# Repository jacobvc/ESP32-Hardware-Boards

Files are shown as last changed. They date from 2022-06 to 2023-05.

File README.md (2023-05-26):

# Esp32 Dev Module Hardware Boards
This repository contains hardware and circuit board designs to simplify ESP32 Dev Module peripheral device connectivity

I think that I have about average circuit board design and soldering skills for an (older) mechanical engineer. As currently, mostly a hobbiest developer, I tend to develop reusable functionality focused circuit boards as opposed to project specific circuit boards. My soldering skills are OK for 0.1 inch center parts. 0805 surface mount parts are at or beyond my limit.

I am sharing these eagle board designs that I have found to be useful; mostly as a sort of tidy bridge between a breadboard and a project specific design. Unless otherwise specified, they are for (30 pin) ESP32 Dev Module boards.

All of the boards are designed using eagle, and any of them can be ordered in many ways, including by going to the [OSH park web site](https://oshpark.com/) and uploading the appropriate .brd file

## Esp32 Dev Module Pins
This design consists of two 15 pin pin headers; ESP32-LEFT and ESP32-RIGHT, with wires and labels corresponding to pin functionality. They are not 'connected' to one-another and are generally intended to be used as a quick start in laying out a board for one or the other side of an ESP32 Dev Module. 

## [ESP32 Lcd 3.5 Connectors](Lcd3.5Connectors)
This design connects the right side of an ESP32 Dev Module (ESP32-RIGHT) to a LCD touch screen display. The display uses all of the GPIOs on that side except two. A four pin connector supports connecting the display mounted SD socket using a shared SPI. The two unused ports are routed to a four pin I2C connector. 

[Used with this display](http://www.lcdwiki.com/3.5inch_SPI_Module_ILI9488_SKU:MSP3520)

## [ESP32 I/O Adapter](Esp32IoAdapt)
This design connects the left side of an ESP32 Dev Module to JST ZH 1.5mm keyed connectors. 

The connectors include
0.1 inch connectors
* 1 each 2 pin GS connector  (switch)
* 1 each 3 pin GVS connector (servo motor, etc). 

JST ZH 1.5mm keyed connectors. 
* 2 each 3 pin GVI connectors (potentiometer, etc). 
* 1 each 4 pin GVSS connector (serial port, I2C, etc)
* 1 each 5 pin GVIIS connectors (joystick, misc)
* 1 each 5 pin GVSSS connectors (joystick, misc)

Note:
*  GVS.. == Ground / 3v3 / Sense GPIO
*  GVI.. == Ground / 3v3 / Input only GPIO
## [ESP32 Audio / Relay Adapter](Esp32Relays)
This design connects left side of an esp32 Dev Module to:
* A three channel relay board
* A CD4066 based analog switch. Two channels of the CD4066 are connected to 3.5mm TRS (input / output) audio connectors, and the other two are available on a pair of 0.1 in center 3 pin headers.
* A 3 pin G5VS connector intended to be used for Neopixel Matrix Display
* Two 3 pin GVS connectors available for general use

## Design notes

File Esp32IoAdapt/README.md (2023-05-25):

# ESP32 I/O Adapter

A relatively small footprint approach to make the I/O pins on the "LEFT_SIDE" of a ESP32 Dev Module available.

Consists of circuit board designs, a (src) header file, and examples.

## Boards
An Esp32IoAdapt board, supported by two other trivial boards to ease connectivity with thumb joysticks and slider potentiometers.

**Esp32IoAdapt** contains a ESP-32 "LEFT_SIDE" board that present the I/O pins on the left side of 
a ESP32 Dev Module as (mostly) JST ZH 1.5mm connectors.

**Joystick** contains a joystick adapter a joystick to the other end of a 5 pin connector.

**Slider** contains an adapter to mount and connect a 35mm slider potentiometer to the other end of a 3 pin connector.

### Esp32IoAdapt
0.1 inch connectors
* 1 each 2 pin GS connector  (switch)
* 1 each 3 pin GVS connector (servo motor, etc). 

JST ZH 1.5mm keyed connectors. The connectors include
* 2 each 3 pin GVI connectors (potentiometer, etc). 
* 1 each 4 pin GVSS connector (serial port, I2C, etc)
* 1 each 5 pin GVSSS connectors (joystick, misc)
* 1 each 5 pin GVIIS connectors (joystick, misc)

Note:
*  GVS.. == Ground / 3v3 / Sense GPIO
*  GVI.. == Ground / 3v3 / Input only GPIO
*  The "V" pins are all 3.3v, so they may not be suited for 5V devices such as 5V servo motors

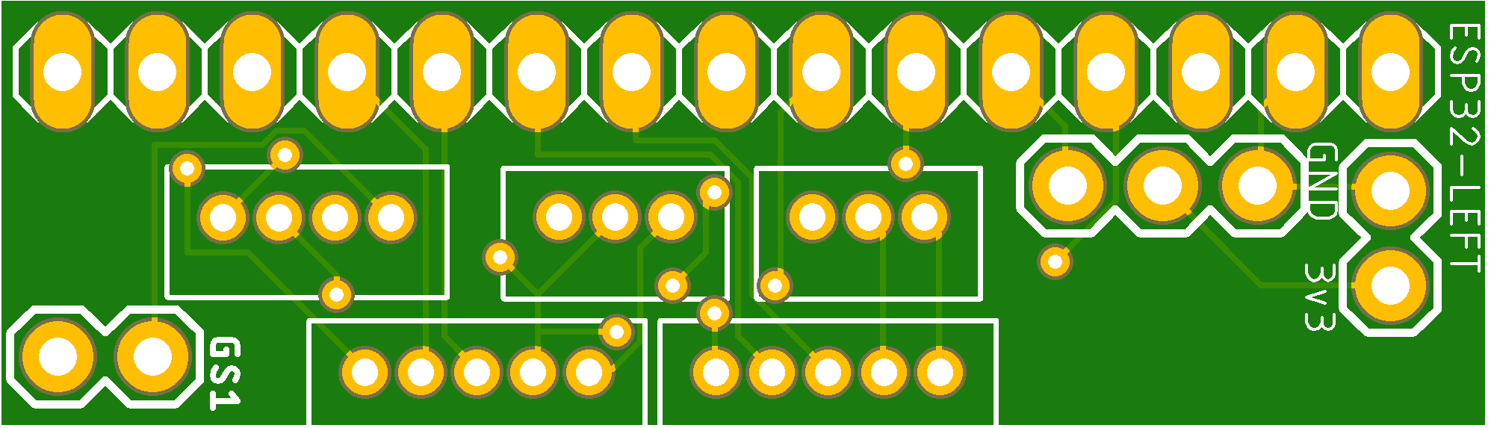
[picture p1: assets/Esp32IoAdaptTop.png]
Top Side Top View

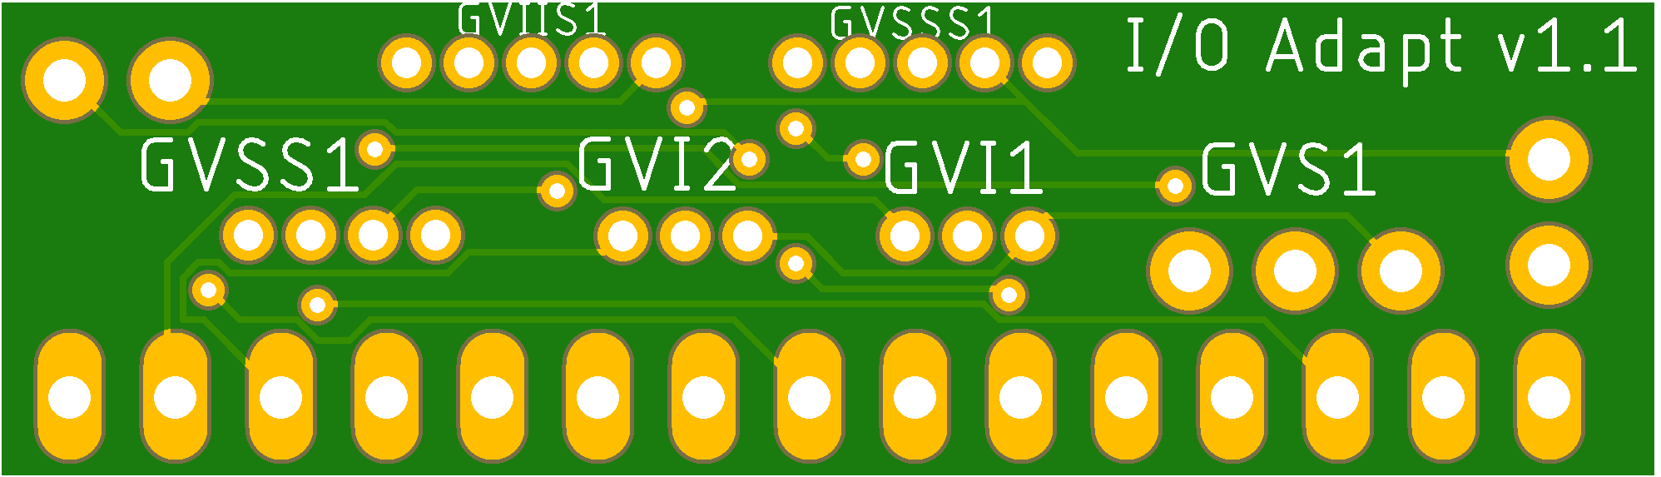
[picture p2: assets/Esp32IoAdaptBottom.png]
Bottom Side Bottom View

Intended to be used with pre-built JST-ZH cables. 
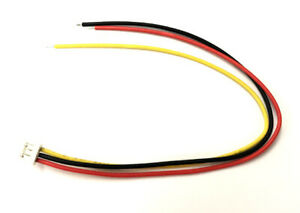
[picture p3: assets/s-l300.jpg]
Cable


### Joystick Adapter
A simple adapter board adapting straight through from 1.5 mm to 0.1 inch. Intended to connect thumb joystick via JST ZH connector 
or soldered wires from JST ZH cable.

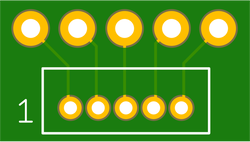
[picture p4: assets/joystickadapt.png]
Joystick adapter


### Slider Adapter
A simple adapter / mounting board for mounting a 35 mm slider potentiometer and connecting via JST ZH connector 
or soldered wires from JST ZH cable.

Slider
Slider adapter

## src
src contains the Esp32IoAdapt.h header file, presented as a component

# Examples
[Esp32IoAdapt is used for the examples](https://github.com/jacobvc/ESP-Object-Messaging/tree/main/examples) in ESP-Object-Messaging.

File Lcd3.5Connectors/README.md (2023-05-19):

# Lcd 3.5 Connectors (v4)
This design connects the right side of an ESP32 Dev Module to a LCD touch screen display. The display uses all of the GPIOs on that side except two. A four pin connector supports connecting the display mounted SD socket using a shared SPI. The two unused ports are routed to a four pin I2C connector. 

[Used with this display](http://www.lcdwiki.com/3.5inch_SPI_Module_ILI9488_SKU:MSP3520); Controller ili9488, Touch controller XPT2046

The hardware connections (for [LVGL V7 driver](https://github.com/lvgl/lv_port_esp32) is supported by these definitions in 'sdconfig'

    CONFIG_LV_TFT_DISPLAY_SPI_VSPI=y
    CONFIG_LV_DISP_SPI_MOSI=4
    # CONFIG_LV_DISPLAY_USE_SPI_MISO is not set
    CONFIG_LV_DISP_SPI_CLK=17
    CONFIG_LV_DISP_SPI_CS=19
    CONFIG_LV_DISP_PIN_DC=5
    CONFIG_LV_DISP_PIN_RST=18
    CONFIG_LV_TOUCH_DRIVER_PROTOCOL_SPI=y
    # CONFIG_LV_TOUCH_CONTROLLER_SPI_HSPI is not set
    CONFIG_LV_TOUCH_CONTROLLER_SPI_VSPI=y

    #
    # Touchpanel (XPT2046) Pin Assignments
    #
    CONFIG_LV_TOUCH_SPI_MISO=2
    CONFIG_LV_TOUCH_SPI_MOSI=4
    CONFIG_LV_TOUCH_SPI_CLK=17
    CONFIG_LV_TOUCH_SPI_CS=16
    # CONFIG_LV_TOUCH_PIN_IRQ is not set
    # end of Touchpanel (XPT2046) Pin Assignments

And separately to use the on-display-board SD Card Socket:

    #define LCD_BACKLIGHT_PIN 15
    #define SHARED_SPI_SD_CS_PIN 22
    #define SHARED_SPI_SD_HOST VSPI_HOST // same as LCD

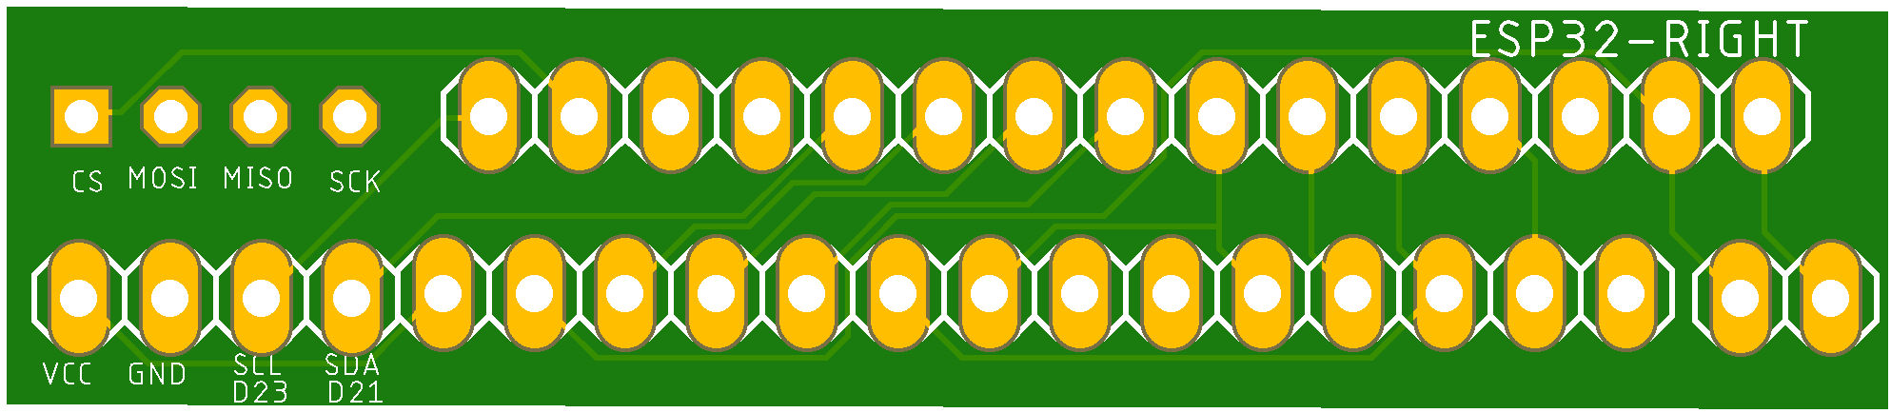
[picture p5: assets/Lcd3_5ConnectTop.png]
Top Side

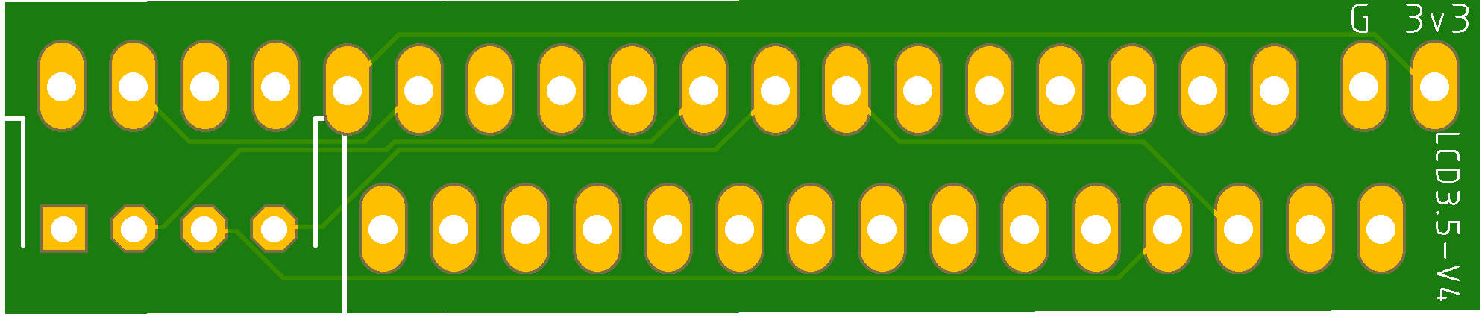
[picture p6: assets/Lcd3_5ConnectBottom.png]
Bottom Side


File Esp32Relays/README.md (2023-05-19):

# Esp32 Relays Board
This design utilizes the left side of an ESP32 Dev Module for:

* A three channel relay board
* A CD4066 based analog switch. Two channels of the CD4066 are connected to 3.5mm TRS (input / output) audio connectors, and the other two are available on a pair of 0.1 in center 3 pin headers.
* A 3 pin (Ground, 5V, and Data on D32) connector intended to be used for Neopixel Matrix Display
* Two 3 pin (Ground, 3.3v, D25 or D26) connectors available for general use

A 3 pin Power connector is provided for **REQUIRED 3.3v input** (from the other side of the ESP32) and optional 5V power for when the system is not being powered by the ESP32 built in USB

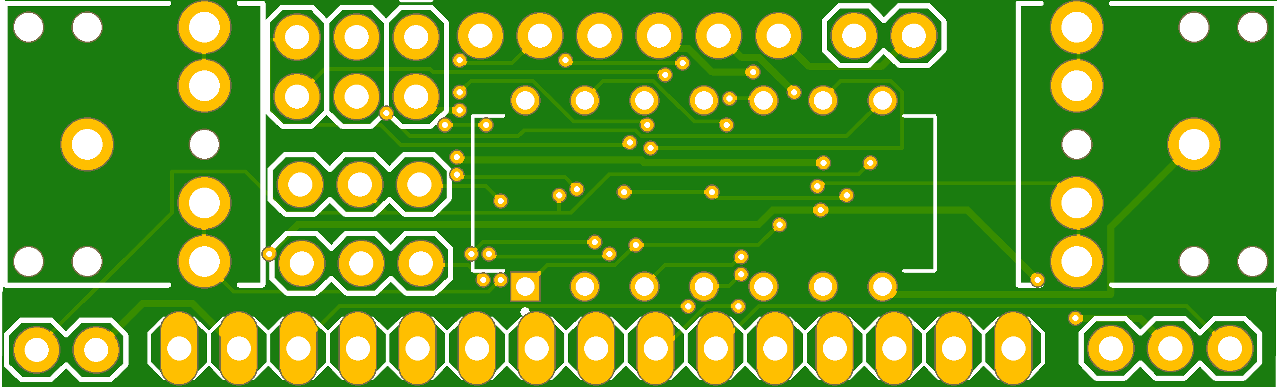
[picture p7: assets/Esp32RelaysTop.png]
Top View<br><br>
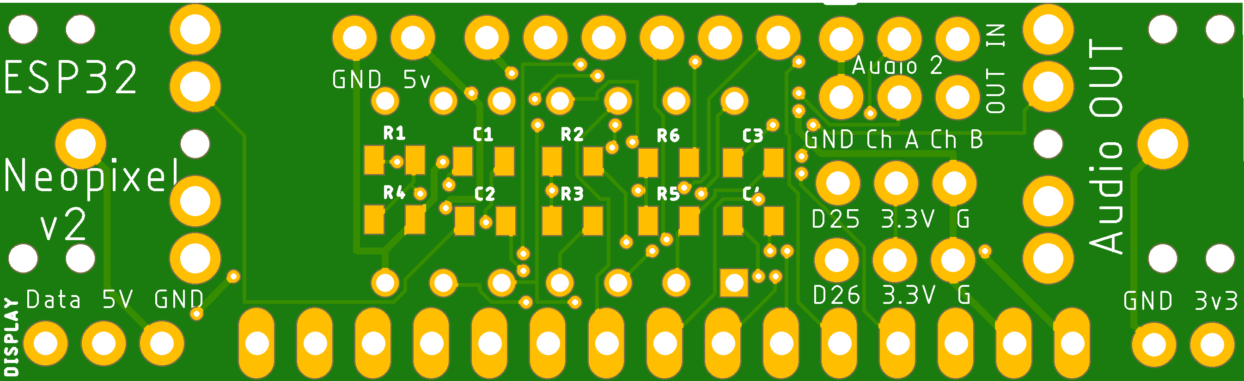
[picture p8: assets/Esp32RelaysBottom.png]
Bottom View<br>

## Components
The components required to assemble the board are:
* One each ESP32 WROOM Development Module
* One each 3 channel relay board
* One each 3 pin JSC SM Male connector with cable
* One each CD4066 ananlog switch
* Two each PJ-307 Audio jacks
* Two each (R1, R4) 4.7k 0805 resistors
* Four Each (R2, R3, R5, R6) 100k 0805 resistors
* Four Each (C1, C2, C3, C4) 1uf 0805 capacitors
* 0.1 center pin headers as desired

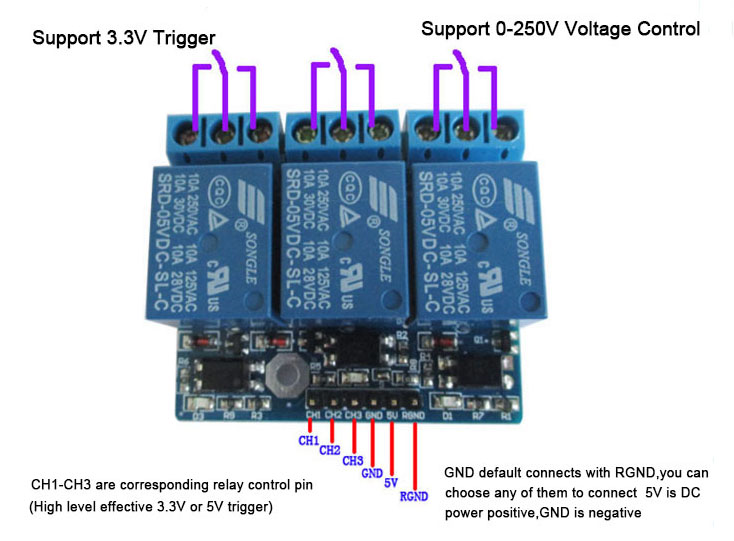
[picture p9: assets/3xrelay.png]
The board is designed to use this three channel relay, which requires a 5V supply but supports 3.3v logic.<br><br>

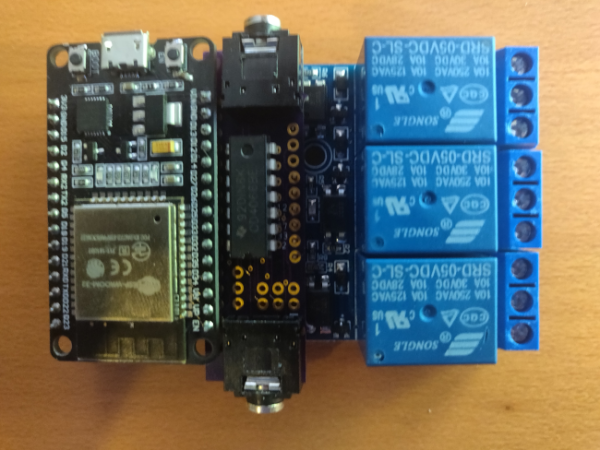
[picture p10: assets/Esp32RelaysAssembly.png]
The assembly looks like this (with the larger components set in place but not soldered).<br>

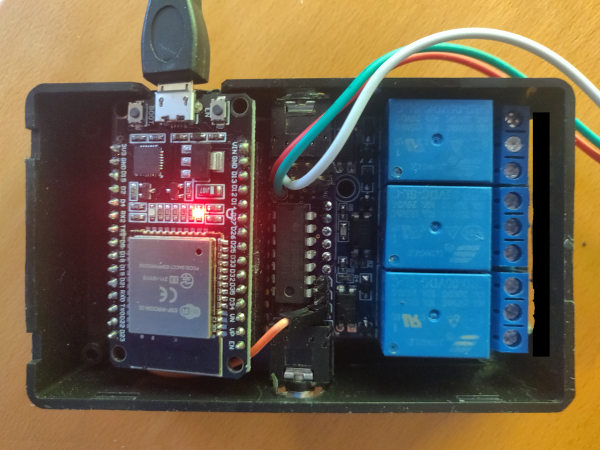
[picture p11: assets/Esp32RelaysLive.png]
The assembled components fit nicely into a 100 x 60 x 25 mm project box. The audio jacks are about 60.5 mm end to end, so you spread the case and they snap into place and help secure the assembly.<br>

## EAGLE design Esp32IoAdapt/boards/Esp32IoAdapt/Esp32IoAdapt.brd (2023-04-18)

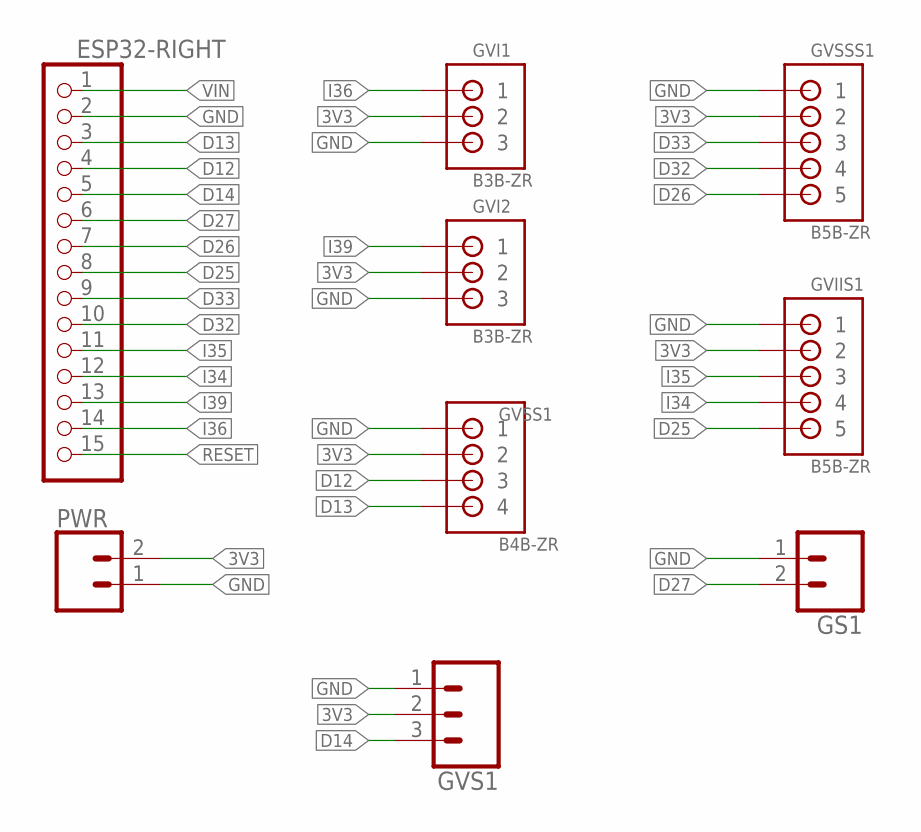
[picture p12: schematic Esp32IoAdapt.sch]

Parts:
ESP32-RIGHT: 0; 1X15
GS1: CONN_02; 1X02
GVI1, GVI2: B3B-ZR
GVIIS1: B5B-ZR
GVS1: CONN_03; 1X03
GVSS1: B4B-ZR
GVSSS1: B5B-ZR
PWR: CONN_02; 1X02

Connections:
3V3: GVI1.2, GVI2.2, GVIIS1.2, GVS1.2, GVSS1.2, GVSSS1.2, PWR.2
D12: ESP32-RIGHT.4, GVSS1.3
D13: ESP32-RIGHT.3, GVSS1.4
D14: ESP32-RIGHT.5, GVS1.3
D25: ESP32-RIGHT.8, GVIIS1.5
D26: ESP32-RIGHT.7, GVSSS1.5
D27: ESP32-RIGHT.6, GS1.2
D32: ESP32-RIGHT.10, GVSSS1.4
D33: ESP32-RIGHT.9, GVSSS1.3
GND: ESP32-RIGHT.2, GS1.1, GVI1.3, GVI2.3, GVIIS1.1, GVS1.1, GVSS1.1, GVSSS1.1, PWR.1
I34: ESP32-RIGHT.12, GVIIS1.4
I35: ESP32-RIGHT.11, GVIIS1.3
I36: ESP32-RIGHT.14, GVI1.1
I39: ESP32-RIGHT.13, GVI2.1
RESET: ESP32-RIGHT.15
VIN: ESP32-RIGHT.1

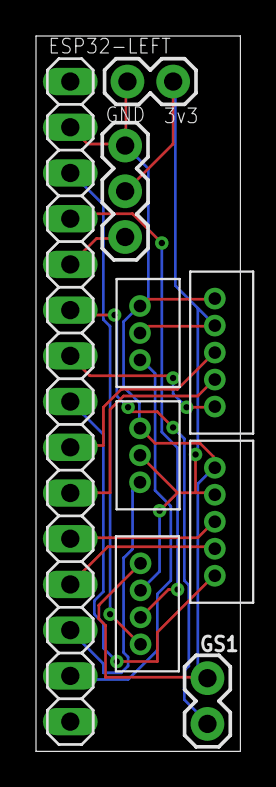
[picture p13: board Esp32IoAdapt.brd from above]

Board: 2 copper layers, 11.4 x 39.7 mm, 9 parts (0 on the bottom side), 14 nets.

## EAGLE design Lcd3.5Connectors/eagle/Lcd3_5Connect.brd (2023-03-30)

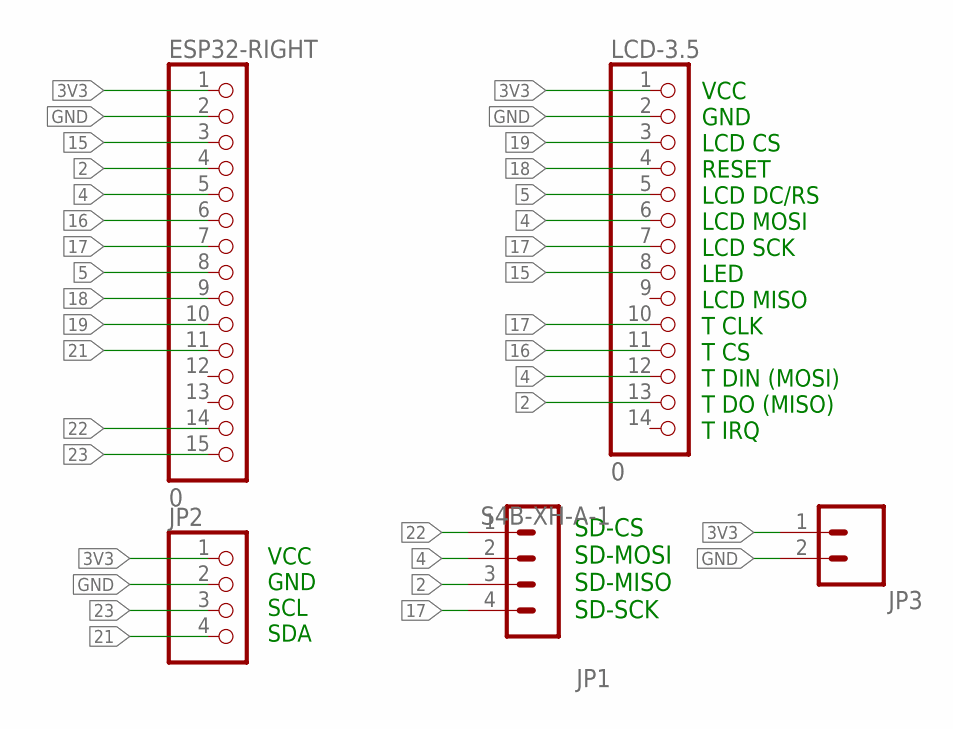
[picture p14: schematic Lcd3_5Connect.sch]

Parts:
ESP32-RIGHT: 0; 1X15
JP1: S4B-XH-A-1
JP2: PINHD-1X4; 1X04
JP3: CONN_02; 1X02
LCD-3.5: 0; 1X14

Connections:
2: ESP32-RIGHT.4, JP1.3, LCD-3.5.13
3V3: ESP32-RIGHT.1, JP2.1, JP3.1, LCD-3.5.1
4: ESP32-RIGHT.5, JP1.2, LCD-3.5.6, LCD-3.5.12
5: ESP32-RIGHT.8, LCD-3.5.5
15: ESP32-RIGHT.3, LCD-3.5.8
16: ESP32-RIGHT.6, LCD-3.5.11
17: ESP32-RIGHT.7, JP1.4, LCD-3.5.7, LCD-3.5.10
18: ESP32-RIGHT.9, LCD-3.5.4
19: ESP32-RIGHT.10, LCD-3.5.3
21: ESP32-RIGHT.11, JP2.4
22: ESP32-RIGHT.14, JP1.1
23: ESP32-RIGHT.15, JP2.3
GND: ESP32-RIGHT.2, JP2.2, JP3.2, LCD-3.5.2

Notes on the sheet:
VCC GND LCD CS RESET LCD DC/RS LCD MOSI LCD SCK LED LCD MISO T CLK T CS T DIN (MOSI) T DO (MISO) T IRQ
SD-CS SD-MOSI SD-MISO SD-SCK
VCC GND SCL SDA

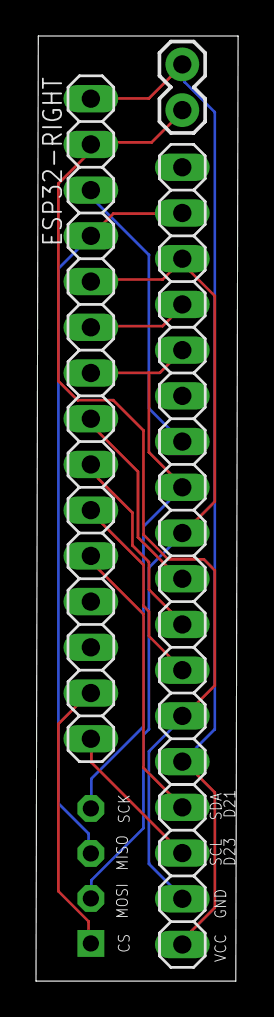
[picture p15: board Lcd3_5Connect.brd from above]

Board: 2 copper layers, 11.2 x 52.5 mm, 5 parts (1 on the bottom side), 13 nets.

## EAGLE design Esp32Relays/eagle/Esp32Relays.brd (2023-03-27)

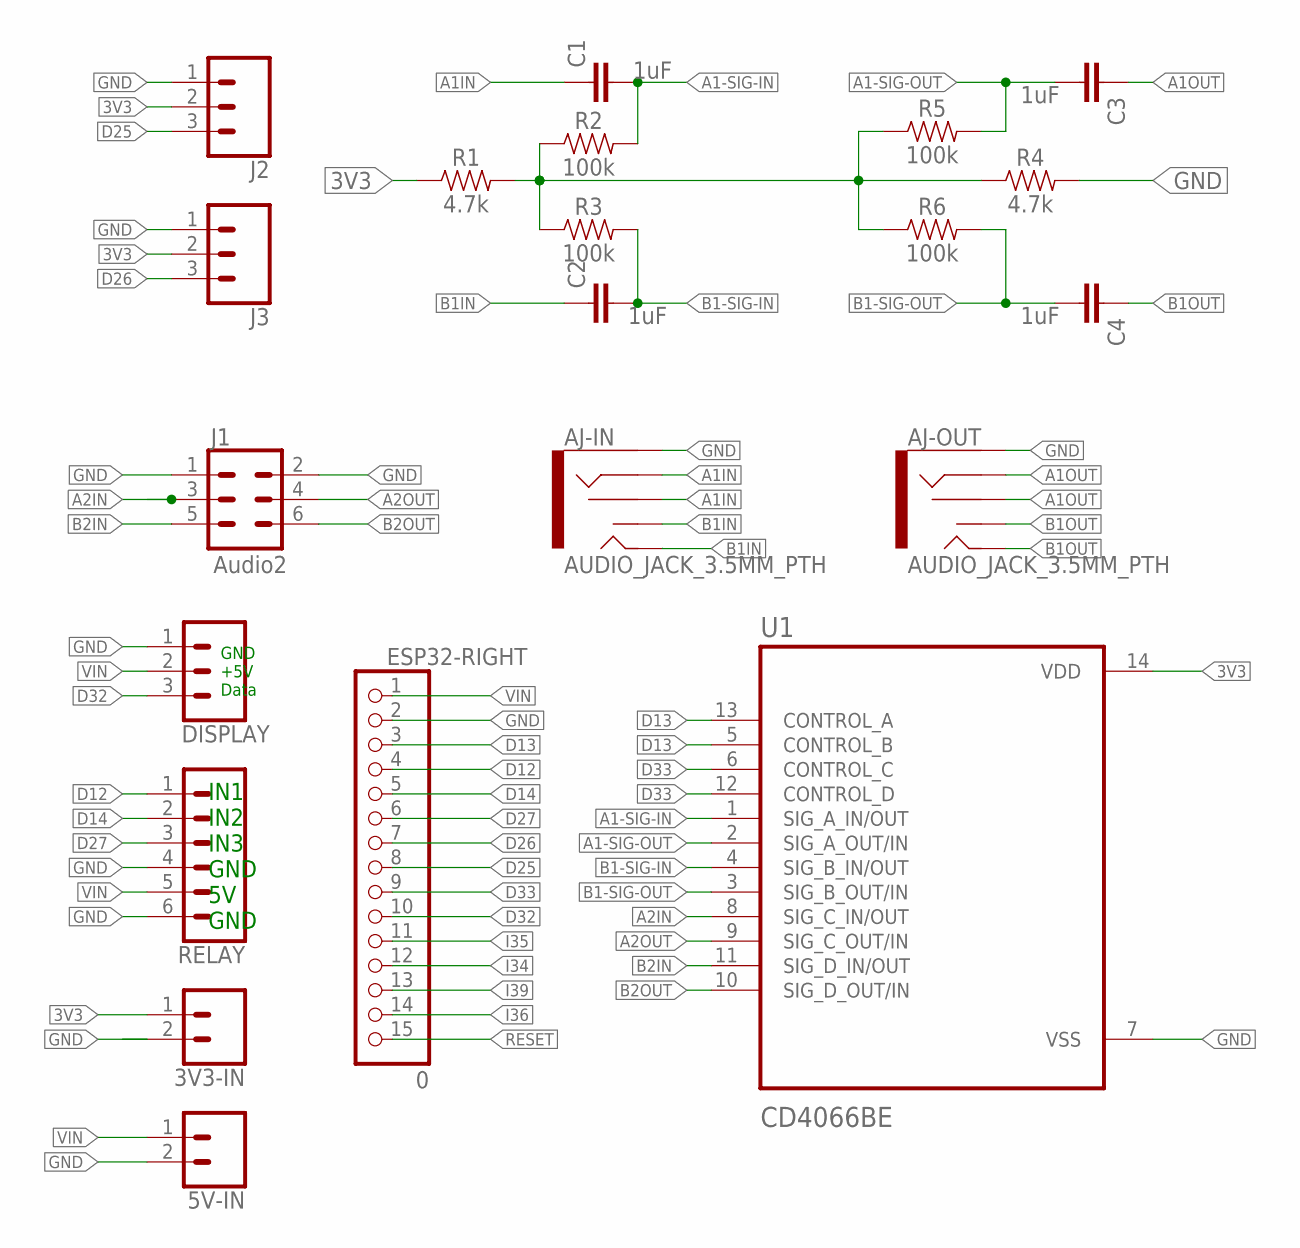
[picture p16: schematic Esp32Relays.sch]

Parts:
3V3-IN, 5V-IN: CONN_02; 1X02
AJ-IN: AUDIO_JACK_3.5MM_PTH; AUDIO-JACK
AJ-OUT: AUDIO_JACK_3.5MM_PTH; AUDIO-JACK
C1, C2, C3, C4: 1uF; 0805
DISPLAY: CONN_03; 1X03
ESP32-RIGHT: 0; 1X15
J1: Audio2; 2X3
J2, J3: CONN_03; 1X03
R1, R4: 4.7k; 0805
R2, R3, R5, R6: 100k; 0805
RELAY: CONN_06NO_SILK_FEMALE_PTH; 1X06_NO_SILK
U1: CD4066BE; DIP794W45P254L1969H508Q14

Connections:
3V3: 3V3-IN.1, J2.2, J3.2, R1.1, U1.14 (VDD)
A1-SIG-IN: C1.2, R2.2, U1.1 (SIG_A_IN/OUT)
A1-SIG-OUT: C3.2, R5.2, U1.2 (SIG_A_OUT/IN)
A1IN: AJ-IN.RING, AJ-IN.RSH, C1.1
A1OUT: AJ-OUT.RING, AJ-OUT.RSH, C3.1
A2IN: J1.3, U1.8 (SIG_C_IN/OUT)
A2OUT: J1.4, U1.9 (SIG_C_OUT/IN)
B1-SIG-IN: C2.2, R3.2, U1.4 (SIG_B_IN/OUT)
B1-SIG-OUT: C4.2, R6.2, U1.3 (SIG_B_OUT/IN)
B1IN: AJ-IN.TIP, AJ-IN.TSH, C2.1
B1OUT: AJ-OUT.TIP, AJ-OUT.TSH, C4.1
B2IN: J1.5, U1.11 (SIG_D_IN/OUT)
B2OUT: J1.6, U1.10 (SIG_D_OUT/IN)
D12: ESP32-RIGHT.4, RELAY.1
D13: ESP32-RIGHT.3, U1.5 (CONTROL_B), U1.13 (CONTROL_A)
D14: ESP32-RIGHT.5, RELAY.2
D25: ESP32-RIGHT.8, J2.3
D26: ESP32-RIGHT.7, J3.3
D27: ESP32-RIGHT.6, RELAY.3
D32: DISPLAY.3, ESP32-RIGHT.10
D33: ESP32-RIGHT.9, U1.6 (CONTROL_C), U1.12 (CONTROL_D)
GND: 3V3-IN.2, 5V-IN.2, AJ-IN.SLEEVE, AJ-OUT.SLEEVE, DISPLAY.1, ESP32-RIGHT.2, J1.1, J1.2, J2.1, J3.1, R4.2, RELAY.4, RELAY.6, U1.7 (VSS)
I34: ESP32-RIGHT.12
I35: ESP32-RIGHT.11
I36: ESP32-RIGHT.14
I39: ESP32-RIGHT.13
unnamed: R1.2, R2.1, R3.1, R4.1, R5.1, R6.1
RESET: ESP32-RIGHT.15
VIN: 5V-IN.1, DISPLAY.2, ESP32-RIGHT.1, RELAY.5

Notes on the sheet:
IN1 IN2 IN3 GND 5V GND
GND +5V Data

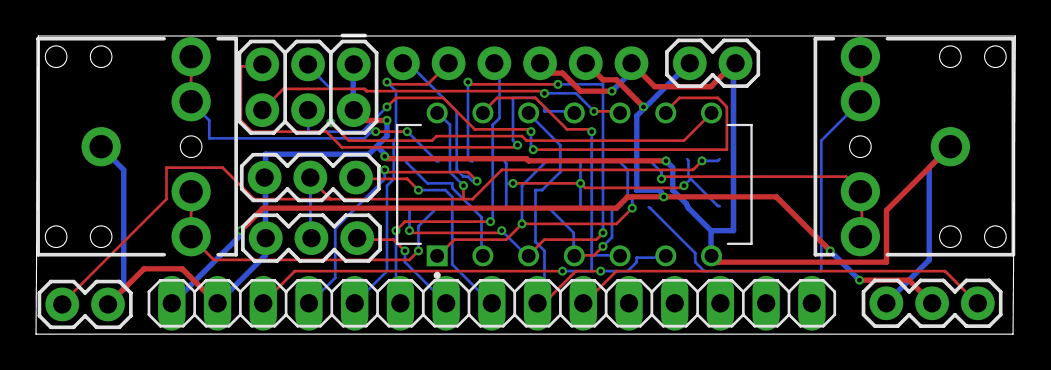
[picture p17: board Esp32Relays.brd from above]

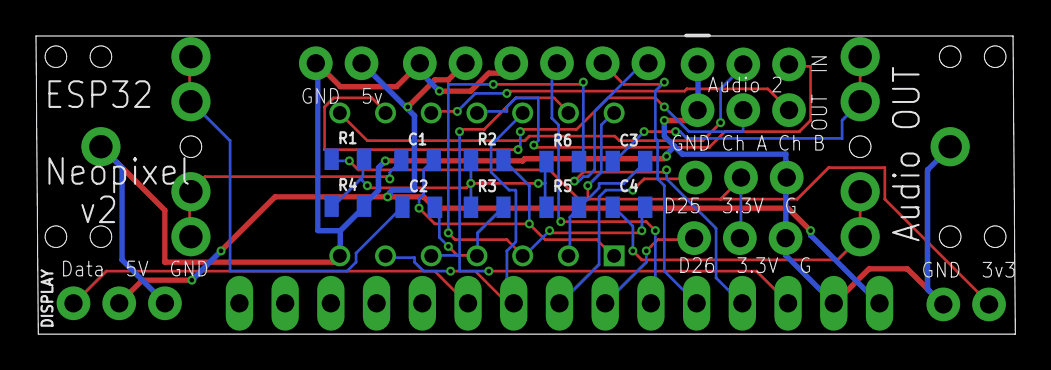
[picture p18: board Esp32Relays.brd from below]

Board: 2 copper layers, 54.4 x 16.6 mm, 21 parts (10 on the bottom side), 24 nets.

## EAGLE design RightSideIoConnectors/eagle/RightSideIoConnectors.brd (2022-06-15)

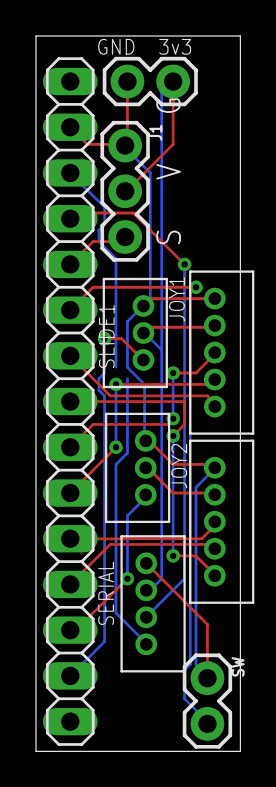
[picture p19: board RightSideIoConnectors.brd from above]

Board: 2 copper layers, 11.4 x 39.7 mm, 9 parts (0 on the bottom side), 14 nets.

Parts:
ESP32-RIGHT: 0; 1X15
J1: 1X03
JOY1, JOY2: B5B-ZR
PWR: 1X02
SERIAL: B4B-ZR
SLIDE1, SLIDE2: B3B-ZR
SW: 1X02

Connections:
3V3: J1.2, JOY1.2, JOY2.2, PWR.2, SERIAL.2, SLIDE1.2, SLIDE2.2
D12: ESP32-RIGHT.4, SERIAL.3
D13: ESP32-RIGHT.3, SERIAL.4
D14: ESP32-RIGHT.5, J1.3
D25: ESP32-RIGHT.8, JOY2.5
D26: ESP32-RIGHT.7, JOY1.5
D27: ESP32-RIGHT.6, SW.2
D32: ESP32-RIGHT.10, JOY1.4
D33: ESP32-RIGHT.9, JOY1.3
GND: ESP32-RIGHT.2, J1.1, JOY1.1, JOY2.1, PWR.1, SERIAL.1, SLIDE1.1, SLIDE2.1, SW.1
I34: ESP32-RIGHT.12, JOY2.4
I35: ESP32-RIGHT.11, JOY2.3
I36: ESP32-RIGHT.14, SLIDE1.3
I39: ESP32-RIGHT.13, SLIDE2.3

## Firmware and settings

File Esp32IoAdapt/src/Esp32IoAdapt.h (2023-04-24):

// NO CONNECTION == GPIO_NUM_NC
#define ACD_CHAN_NC ((adc_channel_t)-1)

/* Connector definitions
 *
 * Naming prefix for this Esp32 I/O Adapter Board is IA_
 *
 * Each connector contains GROUND, optional 3.3 Volt supply and one or more signals
 * 
 * Subsequent pins are "Signal" GPIO's.
 * A full featured signal GPIO is referred to as "S", and an input only signal GPIO is 
 * referred to as "I". 
 * 
 * A connector is named by its signals and instance, e.g. GVS1, 
 * GVI1, GVI2, GVSS1, etc. This name is on the board silkscreen
 * 
 * Each signal GPIO has a pin definition <connector>_PIN, and each analog
 * capable GPIO has a channel definition <connector>_CHAN.
 * 
 * When a connector has a single GPIO, the definitions are literal defines. When a
 * connector has more than one signal, the definitions are plural and represent 
 * arrays (<connector>_PINS[], <connector>_CHANS[]).
 * 
 * For example, a thumb joystick connected to connector GVSSS1 would initialize the 
 * analog channels to GVIIS1_CHAN[0] and GVIIS1_CHAN[1], and the button input to 
 * GVIIS1_PIN[2].
 * 
 */
// GS 1
#define IA_GS1_PIN                GPIO_NUM_27
// GVS 1
#define IA_GVS1_PIN               GPIO_NUM_14
// GVI 1
#define IA_GVI1_PIN               GPIO_NUM_36
#define IA_GVI1_CHAN              ADC_CHANNEL_0
// GVI 2
#define IA_GVI2_PIN               GPIO_NUM_39
#define IA_GVI2_CHAN              ADC_CHANNEL_3
// GVSSI 1
#define IA_GVSS1_PINS  (gpio_num_t[])    {GPIO_NUM_12, GPIO_NUM_13}
// GVSSS 1
#define IA_GVSSS1_PINS (gpio_num_t[])    {GPIO_NUM_33, GPIO_NUM_32, GPIO_NUM_26}
#define IA_GVSSS1_CHANS (adc_channel_t[]) {ADC_CHANNEL_5, ADC_CHANNEL_4, ACD_CHAN_NC}
// GVIIS 1
#define IA_GVIIS1_PINS (gpio_num_t[])    {GPIO_NUM_35, GPIO_NUM_34, GPIO_NUM_25}
#define IA_GVIIS1_CHANS (adc_channel_t[]) {ADC_CHANNEL_7, ADC_CHANNEL_6, ACD_CHAN_NC}

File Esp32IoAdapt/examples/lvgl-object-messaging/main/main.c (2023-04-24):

#include "esp_log.h"
#include "bsp/esp-lcd-3-5-bsp.h"
//#include "lvgl.h"
#include "ui/ui.h"
#include "string.h"

#include "messaging.h"

#define TAG "LCD 3.5 Example"

/***
 *      ____   ____     ____                 _   _____           _   
 *     / ___| |  _ \   / ___| __ _  _ __  __| | |_   _|___  ___ | |_ 
 *     \___ \ | | | | | |    / _` || '__|/ _` |   | | / _ \/ __|| __|
 *      ___) || |_| | | |___| (_| || |  | (_| |   | ||  __/\__ \| |_ 
 *     |____/ |____/   \____|\__,_||_|   \__,_|   |_| \___||___/ \__|
 *                                                                   
 */
#include <stdio.h>
#include "dirent.h"
#define MAX_DIR_BYTES 4096
#define MOUNT_POINT "/sd"

void BtnLsClicked(lv_event_t * e)
{
    const char *path = MOUNT_POINT;
    esp_err_t err = 0;
    lv_textarea_set_text(ui_txaFiles, "");
    sdmmc_card_t *card = bsp_lcd_sdcard_mount(MOUNT_POINT, &err);
    if (card)
    {
        DIR *dir = opendir(path);
        struct dirent *de = readdir(dir);
        lv_label_set_text(ui_lblPath, path);
        while (de)
        {
            lv_textarea_add_text(ui_txaFiles, de->d_name);
            if (de->d_type == DT_DIR)
            {
                lv_textarea_add_text(ui_txaFiles, "/");
            }
            lv_textarea_add_text(ui_txaFiles, "\n");
            de = readdir(dir);
        }
        bsp_lcd_sdcard_unmount(card, MOUNT_POINT);
    }
    else
    {
        lv_label_set_text(ui_lblPath, "Can't read SD Card");
    }
}

/***
 *      ___  ____    ____   _____           _   
 *     |_ _||___ \  / ___| |_   _|___  ___ | |_ 
 *      | |   __) || |       | | / _ \/ __|| __|
 *      | |  / __/ | |___    | ||  __/\__ \| |_ 
 *     |___||_____| \____|   |_| \___||___/ \__|
 *                                              
 */
#include "bmx280.h"

bmx280_t* bmx280 = NULL;

esp_err_t bmp280Init()
{
    bmx280 = bmx280_create(BSP_LCD_I2C_NUM);

    if (!bmx280) { 
        ESP_LOGE(TAG, "Could not create bmx280 driver.");
        return -1;
    }

    esp_err_t err = bmx280_init(bmx280);
    if (err == ESP_OK) {
        bmx280_config_t bmx_cfg = BMX280_DEFAULT_CONFIG;
        err = bmx280_configure(bmx280, &bmx_cfg);
    }
    if (err != ESP_OK) {
        bmx280_close(bmx280);
        bmx280 = NULL;
    }
    return err;
}

void BtnSampleClicked(lv_event_t * e)
{
    if (bmx280) {
        ESP_ERROR_CHECK(bmx280_setMode(bmx280, BMX280_MODE_FORCE));
        do {
            vTaskDelay(pdMS_TO_TICKS(1));
        } while(bmx280_isSampling(bmx280));

        float temp = 0, pres = 0, hum = 0;
        ESP_ERROR_CHECK(bmx280_readoutFloat(bmx280, &temp, &pres, &hum));
        char buf[80];
        sprintf(buf, "%f", pres);
        lv_label_set_text(ui_lblPressure, buf);
        sprintf(buf, "%f", temp);
        lv_label_set_text(ui_lblTemp, buf);
    }
}


/***
 *      ____                _     _  _         _      _     _              _   
 *     | __ )   __ _   ___ | | __| |(_)  __ _ | |__  | |_  | |_  ___  ___ | |_ 
 *     |  _ \  / _` | / __|| |/ /| || | / _` || '_ \ | __| | __|/ _ \/ __|| __|
 *     | |_) || (_| || (__ |   < | || || (_| || | | || |_  | |_|  __/\__ \| |_ 
 *     |____/  \__,_| \___||_|\_\|_||_| \__, ||_| |_| \__|  \__|\___||___/ \__|
 *                                      |___/                                  
 */
#define DEFAULT_BACKLIGHT 60

void SldBacklightChanged(lv_event_t * e)
{
    lv_obj_t * slider = lv_event_get_target(e);
    bsp_lcd_set_brightness((int)lv_slider_get_value(slider));
}

/***
 *                        _        
 *      _ __ ___    __ _ (_) _ __  
 *     | '_ ` _ \  / _` || || '_ \ 
 *     | | | | | || (_| || || | | |
 *     |_| |_| |_| \__,_||_||_| |_|
 *                                 
 */
void app_main(void)
{
    // Initialize display and LVGL
    // WARNING the display is initialized with the backlight off to launch flicker
    // Call bsp_lcd_set_brightness() expicitly to make it visible
    lv_disp_t *disp = bsp_lcd_start();
    lv_disp_set_rotation(disp, LV_DISP_ROT_90); // Landscape

    // Lock the display and iniitialize the SquareLine ui
    bsp_lcd_lock(0);
    ui_init();
    bsp_lcd_unlock();

    // Initialize I2C and BMP280
    bsp_lcd_i2c_init();
    bmp280Init();
    if (!bmx280) {
        lv_label_set_text(ui_lblPressure, "BMP280 NOT FOUND");
        lv_label_set_text(ui_lblTemp, "BMP280 NOT FOUND");
    }

    // Turn on backlight
    lv_slider_set_value(ui_sldBacklight, DEFAULT_BACKLIGHT, LV_ANIM_OFF);
    bsp_lcd_set_brightness(DEFAULT_BACKLIGHT);

    ESP_LOGI(TAG, "Startup Complete.");

    MessagingInit();
}

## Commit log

2022-06-15 Initial Checkin first 3 boards
    [Esp32Left.brd, Esp32Left.sch, Lcd3_5Connect.brd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]
2022-06-15 Fixed directory typo
    [RightSideIoConnectors.brd, RightSideIoConnectors.sch]
2022-06-15 Resized board images
2022-07-04 Minor silkscreen tweak
2022-07-04 Renaming and silkscreen update
    [Esp32IoExpand.brd, Esp32IoExpand.sch]
2022-07-04 Silkscreen tweak
    [Esp32IoAdapt.brd, Esp32IoAdapt.sch]
2022-07-04 Added esp32 relays
    [neopixel.brd, neopixel.sch]
2022-07-04 Neopixel board
    [neopixel.brd, neopixel.sch]
2022-07-04 Schematic update
    [neopixel.brd, neopixel.sch]
2022-07-10 Changed cap values and some labels
    [Esp32Relays.brd, Esp32Relays.sch]
2023-03-11 Changed connector orientation
    [Lcd3_5Connect.brd]
2023-03-21 Added 0.50 space
    [Lcd3_5Connect.brd]
2023-03-21 Added 3v3 / GND connection
    [Lcd3_5Connect.brd, Lcd3_5Connect.sch]
2023-03-22 Update Lcd3_5Connect.brd
    Rotated 3.3v connector
    [Lcd3_5Connect.brd]
2023-03-22 Added 3v connector space
    [Lcd3_5Connect.brd]
2023-03-24 Corrected left vs right nomenclature
    [Esp32IoAdapt.brd, Esp32Pins.brd, Esp32Pins.sch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]
2023-03-27 Added brightness GPIO
    and removed - unused - Touch IRQ pin
    [Esp32Relays.brd, Esp32Relays.sch, Lcd3_5Connect.brd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]
2023-03-27 Updated board image
2023-03-30 Minor dimension tweak
    [Lcd3_5Connect.brd]
2023-03-30 Work on scad output
    [Lcd3_5Connect.brd, Lcd3_5Connect.sch]
2023-04-03 Renamed connectors
    [Esp32IoAdapt.brd, Esp32IoAdapt.sch]
2023-04-03 Adjusted labels
    [Esp32IoAdapt.brd, Esp32IoAdapt.sch]
2023-04-03 More connector labelling
    [Esp32IoAdapt.brd, Esp32IoAdapt.sch]
2023-05-18 Added joystick and slider boards
    [Esp32IoAdapt.brd, Esp32IoAdapt.sch, joystick.brd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]
2023-05-19 Made Esp32IoAdapt into component

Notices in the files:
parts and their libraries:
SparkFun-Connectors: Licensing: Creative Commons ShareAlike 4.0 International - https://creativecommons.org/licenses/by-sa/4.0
